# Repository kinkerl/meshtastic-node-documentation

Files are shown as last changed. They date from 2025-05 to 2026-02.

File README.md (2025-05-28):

# meshtastic-node-documentation

Dies ist eine mögliche Variante offgrid Meshtastic Knoten zu bauen. Siehe auch https://wiki.meshhessen.de/index.php?title=Solar_Node_(Autarker_Meshtastic_Knoten)

## netiquette

Es wird empfohlen der netiquette von meshhessen zu folgen: https://wiki.meshhessen.de/index.php?title=Traffic_Netiquette_f%C3%BCr_Meshtastic

Es gibt dafür hier eine YAML config (`netiquette.yml`) welche alle Konfigurationen schon macht und über die meshtastic python CLI eingespielt werden kann. 

```
 meshtastic --configure netiquette.yml 
```
> [!NOTE]
> Position (Latitude, Longitude, Altitude) und Namen muss danach noch gesetzt werden.

## Shopping

### RAK

* WisBlock Mini Base Board (RAK19003):  https://store.rakwireless.com/products/wisblock-base-board-rak19003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
* Module for LoRaWAN with LoRa SX1262 (RAK4631): https://store.rakwireless.com/products/rak4631-lpwan-node?_pos=1&_sid=6d1fb7b72&_ss=r&variant=37505443823814

> [!NOTE]
> Man kann einfach das Starter-Kit kaufen. Kostet 1€ mehr und man hat dafür ne kleine Antenne dabei: https://store.rakwireless.com/products/wisblock-meshtastic-starter-kit

> [!IMPORTANT]
> Frequenz = EU868 und Variante = RAK4631 Arduino

### Stromversorgung
* Solarmodul 5W 5V: https://de.aliexpress.com/item/1005003823736770.html
  Die 5V Volt sind wichtig. 5 Watt ist ok, 7 Watt oder 10 Watt sind besser bei schlechter Ausrichtung.
* DFRobot Solar Power Manager - Solarenergie-Managementmodul – 5V: https://botland.de/zubehor-fur-solarmodule/14423-dfrobot-solar-power-manager-solarenergie-managementmodul-5v-6959420913473.html
* INA219 I2C Bidirektionaler Gleichstrom-Stromversorgungssensor https://www.amazon.de/dp/B07YDH2PCY/
* Keeppower 26650 7000mAh 3,6V-3,7V Li-Ionen-Akku Mit PCB Schutzelektronik: https://www.akkuteile.de/lithium-ionen-akkus/26650/keeppower/keeppower-26650-7000mah-max-15a-entladestrom-3-6v-3-7v-li-ionen-akku_12119_3605
  
### Antenne
* MikroTik LoRaWAN - Omni Antenne 824-960 MHz:  https://www.omg.de/mikrotik/lorawan/mikrotik-lorawan-omni-antenne-824-960-mhz/a-25277
* Horizon Helium City 868 (anderer Anschluss!): https://interline.pl/de/antennas/HORIZON-HELIUM-CITY-868
* Anderer Anschluss, wenn nötig: https://de.aliexpress.com/item/1005005844592086.html

> [!IMPORTANT]
> Auf ebay Kleinanzeigen werden Teilweise günstige Antennen von alten Helium Minern verkauft. Die nutzen auch 868MHz und kann man benutzen. 

### Gehäuse 
* Ebay von AN3DAS.de:  https://www.ebay.de/itm/335611244498
* oder 3D Druck: https://www.printables.com/model/72839-customizable-parametric-stable-and-waterproof-elec <- sehr schönes Gehäuse!
* oder 3D Druck: https://www.printables.com/model/1012624-w9etc-meshtastic-solar-node <- hab ich genutzt. Passt sehr gut, Dichtung ist nicht optimal.
* Heated Inserst für Gehäuse( M3 x 5mm und M5 x 4mm): https://de.aliexpress.com/item/1005008165093382.html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
 
### Kleinkram
* Dichtung: Schaumstoffstreifen aus Silikonkautschuk, 3mm: https://de.aliexpress.com/item/1005006511018794.html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
* Silikonfett für die Dichtungen: https://www.amazon.de/dp/B00295DBQE
* Wasserdichte Druckausgleichsventile: https://www.aliexpress.com/item/1005007175727622.html?spm=a2g0o.order_list.order_list_main.16.df621802LlLh65
* Kabel mit Stecker für alle Solar/Batterie/Stromverbindungen: https://www.aliexpress.com/item/1005007548578228.html?spm=a2g0o.order_list.order_list_main.39.df621802LlLh65
* Kleber und Dichtmasse zwischen Solarpanel und Gehäuse: Sikaflex 522

## Namesschild

Die Datei `meshhessen_qr_code_name.3mf` ist ein 2-farbiger Druck für ein Namesschild mit QR-Code welcher auf fast jedem Drucker mit einem manuellen Filamentwechsel gedruckt werden kann. Man braucht kein automatisches Filamentwechsel. 
Der Text kann dann, passend zum Node, im slicer angepasst werden. Getestet im Prusa Slicer.
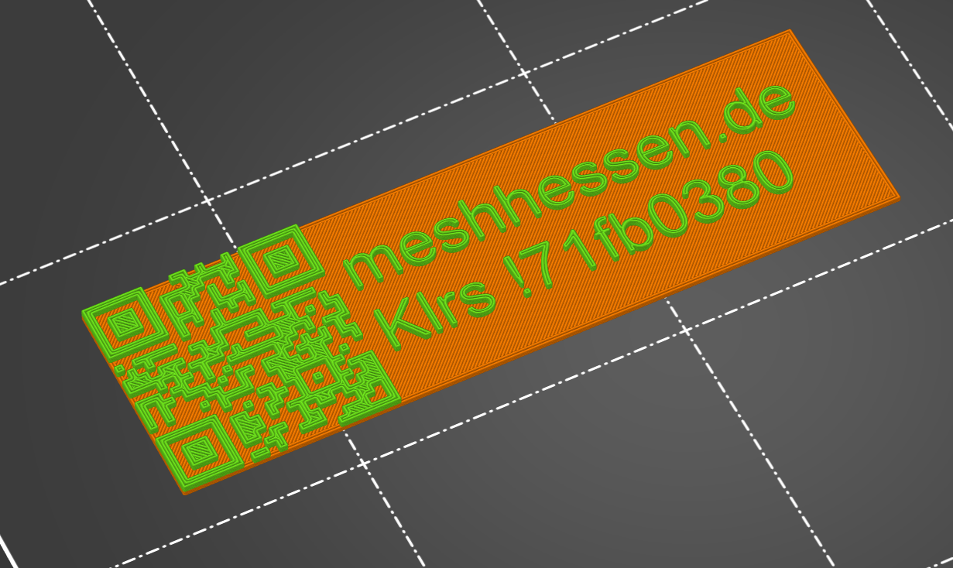
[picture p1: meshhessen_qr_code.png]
QR Code

Das Schild kann dann auf das Gehäuse von außen aufgeklebt werden.

> [!IMPORTANT]
> Für den 2-farbigen Druck sollte man zwei Farben mit einem starken helligkeitsunterschied nutzen. Schwarz und Weiß ist perfekt. In dem Renderbild des QR-Codes sieht man zwar einen starken Kontrast zwischen Grün und Orange, der Grau-wert beider Farben ist aber im Vergleich kontrastarm und die meisten Scanner kommen damit nicht klar. 

## Config Checklist
* Namen und Short
* Frequenz auf Europa
* `netiquette.yml` einspielen
* `channels_and_mqtt.yml` einspielen
* Bluetooth pin verändern
* keys speichern
* remote admin key festlegen

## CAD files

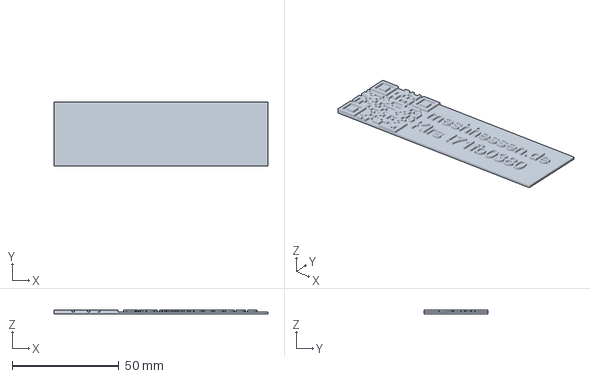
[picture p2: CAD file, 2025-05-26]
meshhessen_qr_code_name.3mf
100.4 x 30.0 x 2.00 mm

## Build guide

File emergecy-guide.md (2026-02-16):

# 📡 Meshtastic-Notfallanleitung (Deutsch)

Diese Anleitung hilft dir, **schnell und einfach** dein Meshtastic-Gerät (Node) mit deinem Smartphone zu verbinden und mit anderen zu kommunizieren – auch **ohne Mobilfunk oder Internet**.

## 🧾 Vorbereitung: Was du brauchst

* Ein Meshtastic Gerät mit Antenne
* Ein Smartphone (Android oder iPhone)
* Die **Meshtastic-App** (kostenlos im App Store oder Play Store)

## 🔌 Vorbereitung: App installieren

1. Öffne den **Google Play Store** oder **Apple App Store**.
2. Suche nach **"Meshtastic"**.
3. Lade die App herunter und installiere sie.

## 🔗 Vorbereitung: Mit dem Node verbinden (Pairing)

1. Schalte Bluetooth am Handy ein.
2. Öffne die Meshtastic-App und wechsele zum letzten Reiter/Tab
3. Dort siehst du alle Geräte mit den du dich schon mal Verbunden hast oder neu verbinden könntest.
4. Das Gerät sucht automatisch nach Nodes in der Umgebung.
5. Wähle deinen Node aus ____________________________ (Name z. B. `meshtastic-XXXX`).
6. Bestätige die Verbindung, wenn gefragt wird. Eventuell muss noch ein Code für das Pairing eingegeben werden. Der Code lautet ____________________________

## 🗨️ Notfallsituation: Nachrichten lesen und senden

1. In dem linken Reiter (Symbol Sprechblase) werden Nachrichten geschrieben und empfangen.
2. Es gibt 2 öffentliche Gruppenchats: "ShortSlow" für den Allgemeiner Chat, sowie "MeshHessen" als Community Chat.
3. Es gibt 1 privaten Gruppenchat. Der Name ist ____________________________
4. Dieser Bereich kann in etwa wie WhatsApp oder Signal benutzt werden

> [!IMPORTANT]
> Es kann etwas dauern bis eine Nachricht geschickt oder empfangen wird. Das Senden kann auch fehlschlagen und der Sendestatus wird als kleines Symbol an der Nachricht angezeigt.

Die Nachricht wird **über Funk** an alle erreichbaren Nodes in deiner Umgebung gesendet – **auch ohne Internet**.

## Probleme: Der "ShortSlow" Gruppenchat ist nicht sichtbar, nur "LongFast".

1. Gehe in die Einstellungen über den Reiter mit dem Zahnrad am unteren Rand
2. Unter "Lora" stelle sicher, dass die Region auf "European Union 868MHz" und Presets auf "Short Range - Slow" steht.

## Probleme: Der "MeshHessen" Gruppenchat ist nicht sichtbar

1. Scanne folgenden QR Code und folge den Anweisungen:

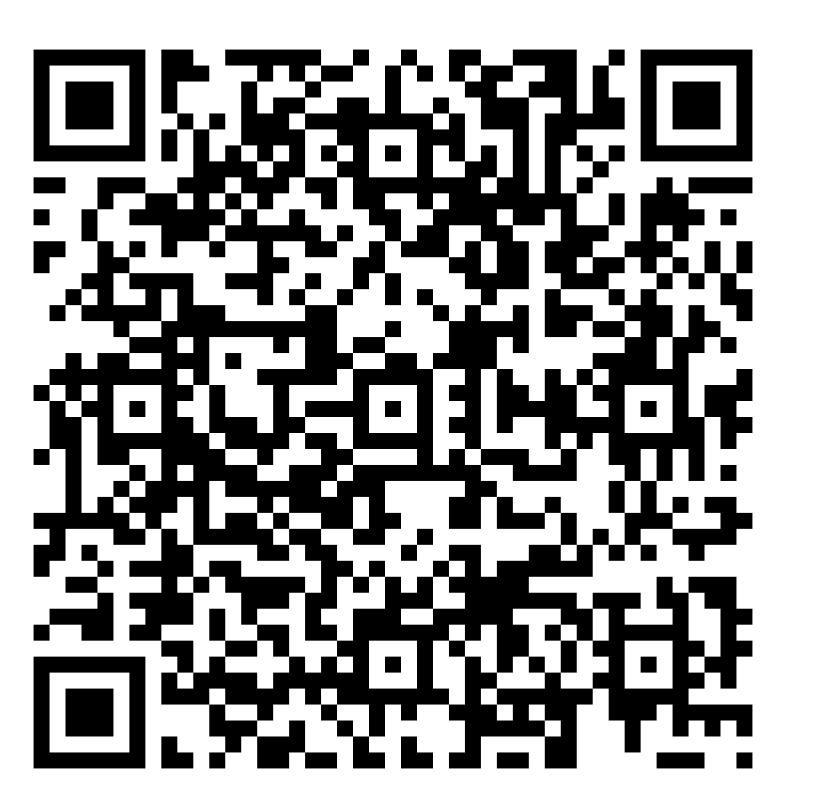
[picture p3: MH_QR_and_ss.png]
MeshHessen QR Code


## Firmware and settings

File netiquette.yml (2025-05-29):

# Opinions in this configuration:
# * This is for a fixed position node. You have to set lat, long and alt
# * This assumes you are using a power measurement hardware (see meshhessen.de community node)
# * It sets the meshhessen.de MQTT server
# * Embraces MQTT and allows sending and receiving via MQTT
# * Deactivates the heartbeat LED to save power

# start of Meshtastic configure yaml
config:
  device:
    ledHeartbeatDisabled: true
    nodeInfoBroadcastSecs: 10800
  lora:
    configOkToMqtt: true
    hopLimit: 3
    region: EU_868
    sx126xRxBoostedGain: true
    txEnabled: true
    txPower: 27
    usePreset: true
  position:
    broadcastSmartMinimumDistance: 100
    broadcastSmartMinimumIntervalSecs: 30
    fixedPosition: true
    gpsUpdateInterval: 120
    positionBroadcastSecs: 21600
    positionFlags: 811
module_config:
  telemetry:
    deviceUpdateInterval: 14400
    powerMeasurementEnabled: true
    powerScreenEnabled: true
    powerUpdateInterval: 14400
